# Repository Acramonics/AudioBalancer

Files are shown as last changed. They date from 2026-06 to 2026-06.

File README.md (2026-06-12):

AudioBalancer
=============

Andrew Martin, acramonics, 2026
-------------------------------

`AudioBalancer` is a balanced line receiver to unbalanced and an
unbalanced to balanced driver on a single board. This could be used as
a standalone device or as an add on to another circuit - the board has
been designed to be as small as possible while using through-hole
components.

A -15V/0/+15V power supply is needed.

The circuit uses the SSM2141P receiver and SSM2142P receiver. These
are now end-of-life, but still quite easy to find quite cheaply.

Both receiver and driver contain capacitors for decoupling 48V phantom
power on the balanced connection protection for the chips if these are
charged and the inputs are accidentally shorted to earth. See the
[Phantom Menace](./docs/AES5335_48V_Phantom_Menace.pdf) document.

| | Components | Value | Function | Options |
| :- | :--- | :---- | :--- | :--- |
| 1  | C3,C4,C13,C14 | 10nF  | HF coupling | Omit if not needed |
| 2  | C1,C2,C11,C12 | 47uF  | Phantom protection  | Bridge if not needed |
| 3  | D1,D2,D3,D4,D5,D6,D7,D8  | SB160 | Short protection | Omit if not needed |
| 4  | R4,R5,R6,R7 | 10K | Short protection | Omit if not needed |

1. The 10nF capacitors across the decoupling capacitors are to ensure
   a good high frequency response. Depending on your application these
   may not be needed.

2. These prevent the 48V phantom power reaching the ICs. If you are
   confident that this is not a problem in your application, they may
   be bridged out.

3. If the 47uF capacitors are charged by phantom power and the signal
   pins are accidentally shorted to ground these provide protection to
   the chips by shunting the voltage to the power rail. Normal 1N4148
   diodes may also be used, but they will not provide the same degree
   of protection.

4. These allow the 47uF capacitors to discharge in the event of a short.

Consequently, if you are confident of no problems with phantom power,
you can omit the eight Schottky diodes, and the four 10K resistors and
replace the four 47uF coupling capacitors with links.

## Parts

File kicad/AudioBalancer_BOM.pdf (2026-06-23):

AudioBalancer_BOM

Page 1

Reference | Qty Value | Footprint
C1,C2,C11,C12 | 4 47uF/63V | Capacitor_THT:CP_Radial_D10.0mm_P5.00mm
C3,C4,C13,C14 | 4 10nF | Capacitor_THT:C_Rect_L7.0mm_W2.0mm_P5.00mm
C5,C6,C7,C8 | 4 100nF | Capacitor_THT:C_Rect_L7.0mm_W2.5mm_P5.00mm
C9,C10 | 2 10uF/16V | Capacitor_THT:CP_Radial_D5.0mm_P2.00mm
C15,C16 | 2 470uF | Capacitor_THT:CP_Radial_D10.0mm_P5.00mm_P7.50mm
D1,D2,D3,D4,D5,D6,D7,D8 | 8 1N4004GP | Diode_THT:D_DO-41_SOD81_P10.16mm_Horizontal
J1,J4,J5 | 3 Conn_01x03_Pin Connector_Molex:Molex_KK-254_AE-6410-03A_1x03_P2.54mm_Vertical
J2,J3 | 2 Conn_01x02_Pin Connector_Molex:Molex_KK-254_AE-6410-02A_1x02_P2.54mm_Vertical
R1 | 1 2K7 | Resistor_THT:R_Axial_DIN0207_L6.3mm_D2.5mm_P10.16mm_Horizontal
R2,R3 | 2 47R | Resistor_THT:R_Axial_DIN0207_L6.3mm_D2.5mm_P10.16mm_Horizontal
R4,R5,R6,R7 | 4 10K | Resistor_THT:R_Axial_DIN0207_L6.3mm_D2.5mm_P10.16mm_Horizontal
U1 | 1 SSM2141 | Package_DIP:DIP-8_W7.62mm
U2 | 1 SSM2142P | Package_DIP:DIP-8_W7.62mm

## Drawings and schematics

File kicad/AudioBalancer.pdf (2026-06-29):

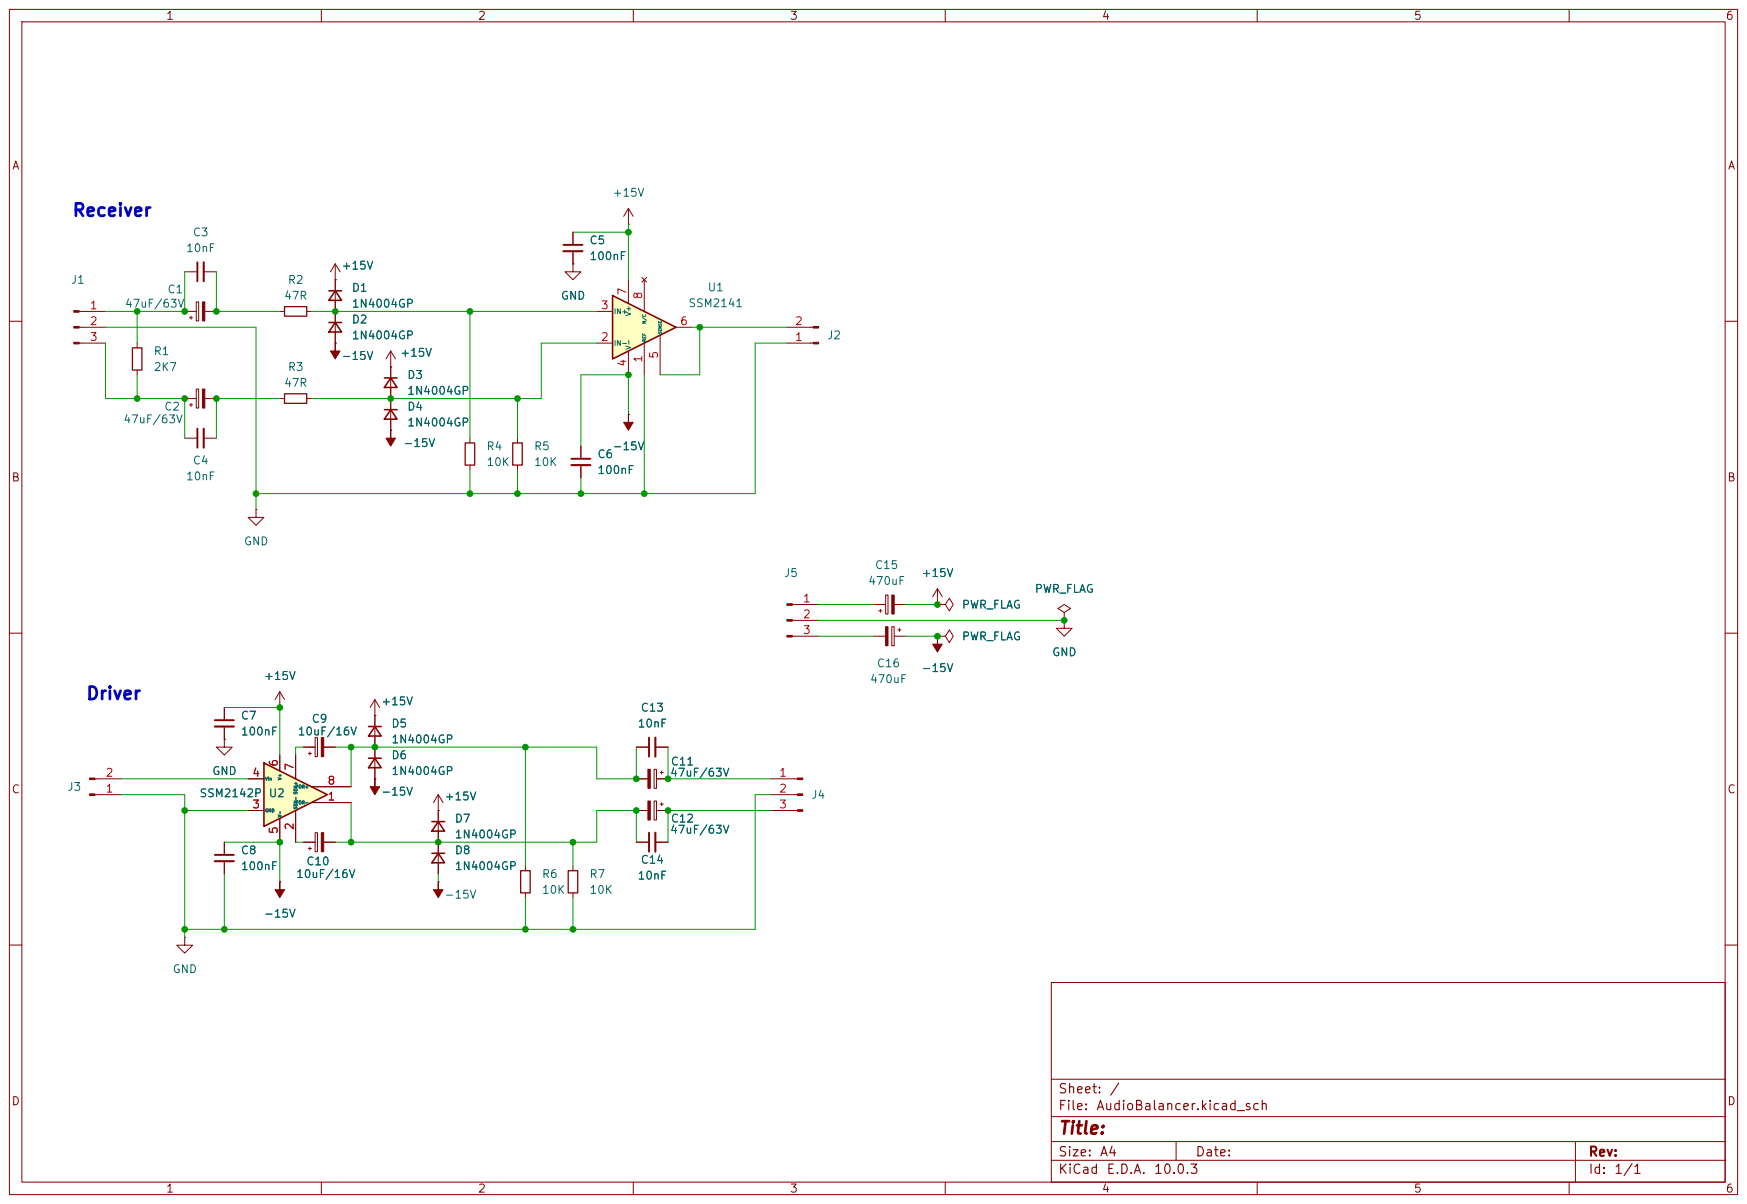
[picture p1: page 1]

Size: A4 | Rev:
KiCad E.D.A. 10.0.3 | Id: 1/1

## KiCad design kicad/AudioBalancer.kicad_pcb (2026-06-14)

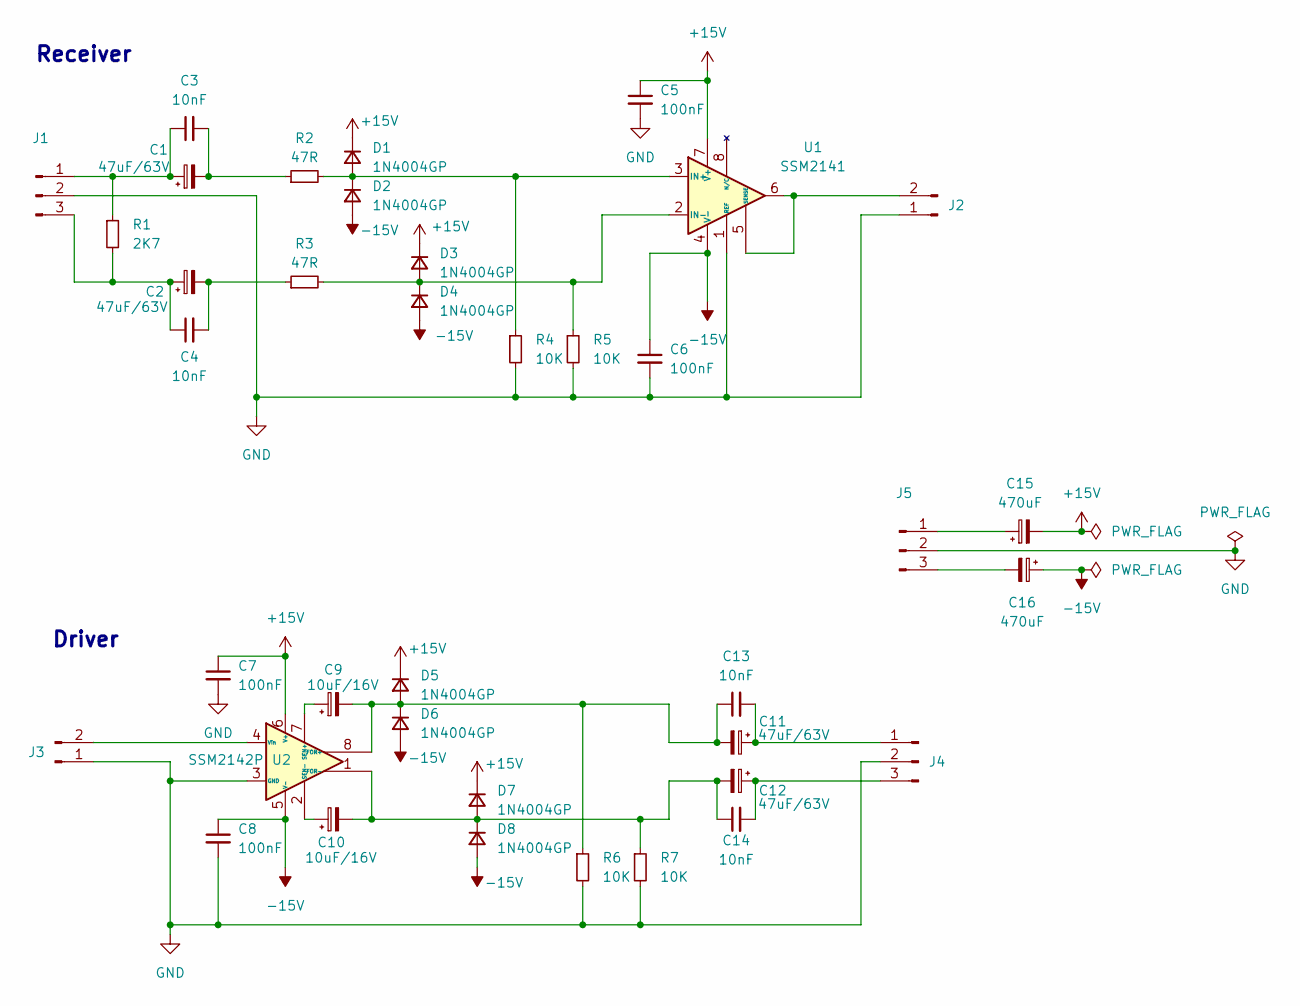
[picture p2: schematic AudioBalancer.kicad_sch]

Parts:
C1, C2, C11, C12: 47uF/63V; CP_Radial_D10.0mm_P5.00mm
C3, C4, C13, C14: 10nF; C_Rect_L7.0mm_W2.0mm_P5.00mm
C5, C6, C7, C8: 100nF; C_Rect_L7.0mm_W2.5mm_P5.00mm
C9, C10: 10uF/16V; CP_Radial_D5.0mm_P2.00mm
C15, C16: 470uF; CP_Radial_D10.0mm_P5.00mm_P7.50mm
D1, D2, D3, D4, D5, D6, D7, D8: 1N4004GP; D_DO-41_SOD81_P10.16mm_Horizontal
J1, J4, J5: Conn_01x03_Pin; Molex_KK-254_AE-6410-03A_1x03_P2.54mm_Vertical
J2, J3: Conn_01x02_Pin; Molex_KK-254_AE-6410-02A_1x02_P2.54mm_Vertical
R1: 2K7; R_Axial_DIN0207_L6.3mm_D2.5mm_P10.16mm_Horizontal
R2, R3: 47R; R_Axial_DIN0207_L6.3mm_D2.5mm_P10.16mm_Horizontal
R4, R5, R6, R7: 10K; R_Axial_DIN0207_L6.3mm_D2.5mm_P10.16mm_Horizontal
U1: SSM2141; DIP-8_W7.62mm
U2: SSM2142P; DIP-8_W7.62mm

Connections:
+15V: C5.1, C7.1, C15.2, D1.1 (K), D3.1 (K), D5.1 (K), D7.1 (K), U1.7 (V+), U2.6 (V+)
-15V: C6.1, C8.1, C16.1, D2.2 (A), D4.2 (A), D6.2 (A), D8.2 (A), U1.4 (V-), U2.5 (V-)
GND: C5.2, C6.2, C7.2, C8.2, J1.2, J2.1, J3.1, J4.2, J5.2, R4.2, R5.2, R6.2, R7.2, U1.1 (REF), U2.3 (GND)
unnamed: C1.2, C3.2, R2.1
unnamed: C2.2, C4.2, R3.1
unnamed: D1.2 (A), D2.1 (K), R2.2, R4.1, U1.3 (IN+)
unnamed: D3.2 (A), D4.1 (K), R3.2, R5.1, U1.2 (IN-)
unnamed: C9.2, C11.2, C13.1, D5.2 (A), D6.1 (K), R6.1, U2.8 (FOR+)
unnamed: C10.2, C12.2, C14.1, D7.2 (A), D8.1 (K), R7.1, U2.1 (FOR-)
unnamed: C1.1, C3.1, J1.1, R1.1
unnamed: C2.1, C4.1, J1.3, R1.2
unnamed: J2.2, U1.5 (SENSE), U1.6
unnamed: J3.2, U2.4 (Vin)
unnamed: C11.1, C13.2, J4.1
unnamed: C12.1, C14.2, J4.3
unnamed: C15.1, J5.1
unnamed: C16.2, J5.3
unnamed: C9.1, U2.7 (SEN+)
unnamed: C10.1, U2.2 (SEN-)

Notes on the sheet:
Receiver
Driver

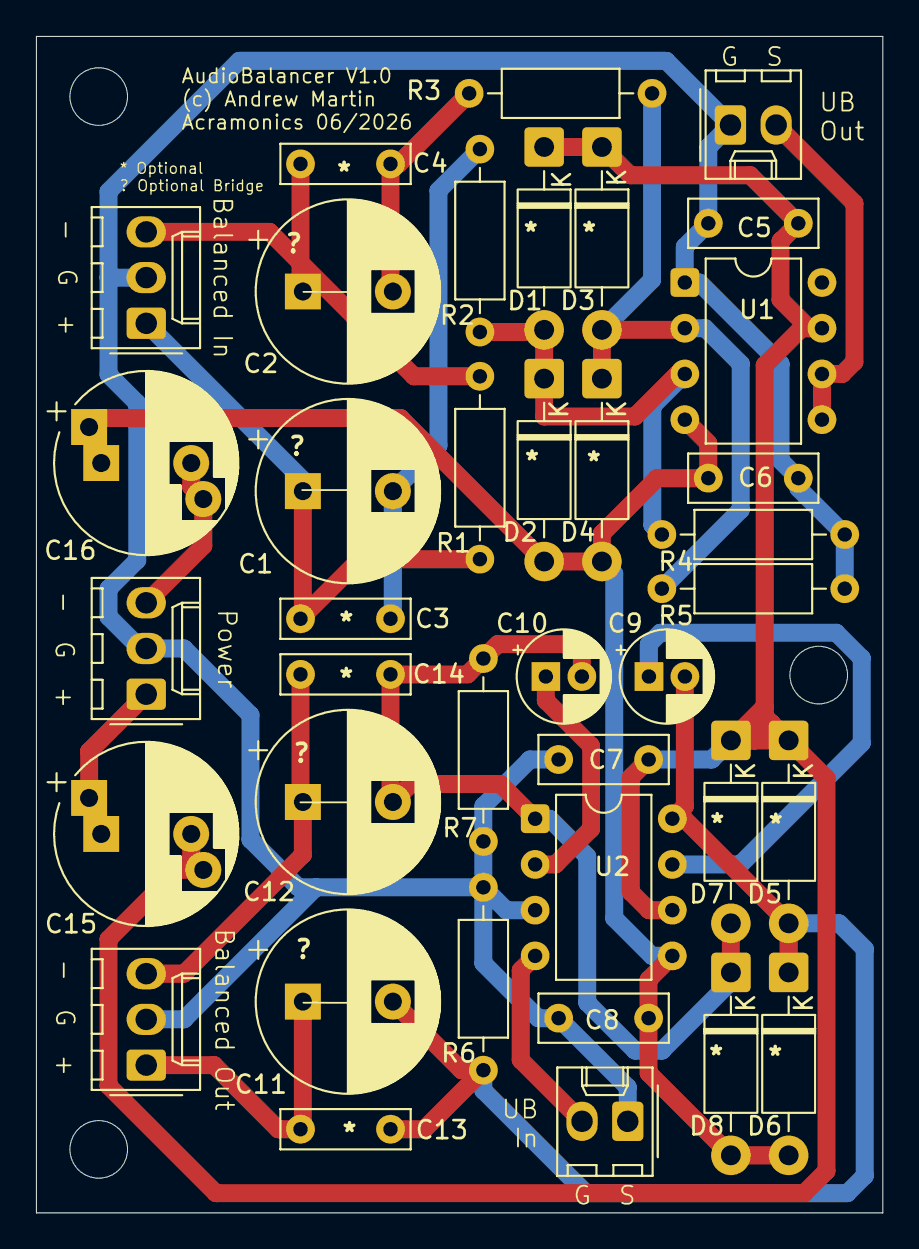
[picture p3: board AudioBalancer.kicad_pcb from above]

Board: 2 copper layers, 47.0 x 65.4 mm, 38 parts (0 on the bottom side), 19 nets.

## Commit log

2026-06-10 First draft
    [AudioBalancer.kicad_pcb, AudioBalancer.kicad_sch]
2026-06-11 Added ppaers on phantom power problems
2026-06-12 Completed V1.0
    [AudioBalancer.kicad_pcb, AudioBalancer.kicad_sch]
2026-06-14 Changed to protection values in 'The 48 Volt Phantom Menace Returns'
    [AudioBalancer.kicad_pcb, AudioBalancer.kicad_sch]
2026-06-23 Added BOM
    [AudioBalancer_BOM.ods]
2026-06-29 Added schematic pdf
